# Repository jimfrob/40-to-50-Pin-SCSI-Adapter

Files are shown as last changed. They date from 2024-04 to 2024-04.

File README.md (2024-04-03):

I had a spare PowerBook version of a BlueSCSI v2 and wanted to make use of it, so I designed a PCB to adapt the 40-pin connector of the PowerBook to the standard 50-pin connector. I then designed a mount for installing it in a computer. The BlueSCSI is intended to be soldered on top of the board with the 40-pin header between. The power connector may be extranneous since the BlueSCSI should be able to take termination power.

40-pin header: Digikey part number [62004021121](https://www.digikey.com/en/products/detail/würth-elektronik/62004021121/15672211?s=N4IgTCBcDaIGxgAyICyLARg5kBdAvkA)

50-pin header: Digikey part number [SBH11-PBPC-D25-ST-BK](https://www.digikey.com/en/products/detail/sullins-connector-solutions/SBH11-PBPC-D25-ST-BK/1990069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)

Any 4-pin header should work for power for use with a floppy drive berg connector.

The board was designed with KiCad 8.



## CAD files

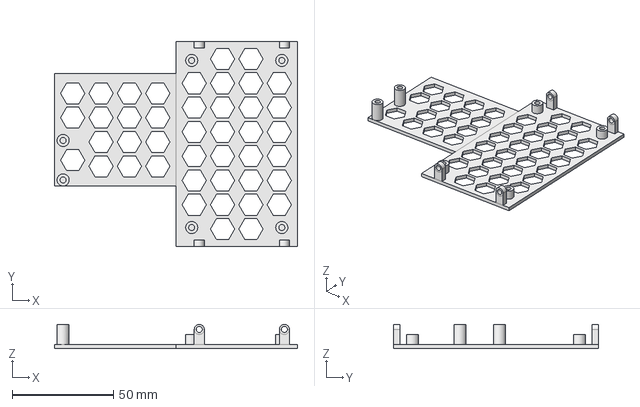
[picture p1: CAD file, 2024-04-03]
SCSI-Adapter-Mount-2.FCStd
120.0 x 101.0 x 12.0 mm

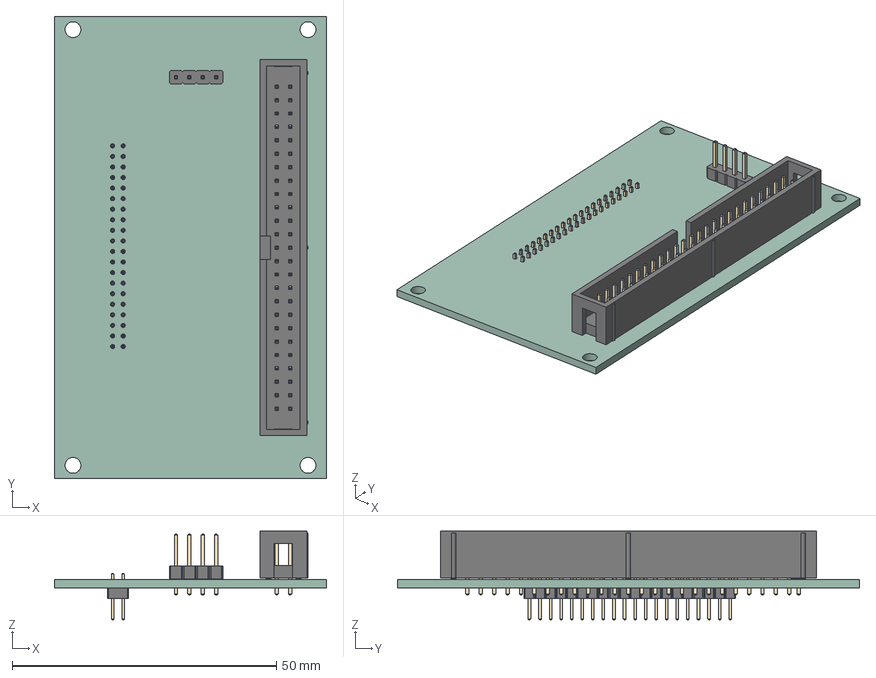
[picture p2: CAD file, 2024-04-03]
SCSI-Adapter.step
51.5 x 87.5 x 16.8 mm
IDC_Header_2x25_P254mm_Vertical
PinHeader_1x04_P254mm_Vertical
PinHeader_2x20_P200mm_Vertical
SCSI-Adapter_PCB

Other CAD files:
SCSI-Adapter-Mount-2-Body.stl

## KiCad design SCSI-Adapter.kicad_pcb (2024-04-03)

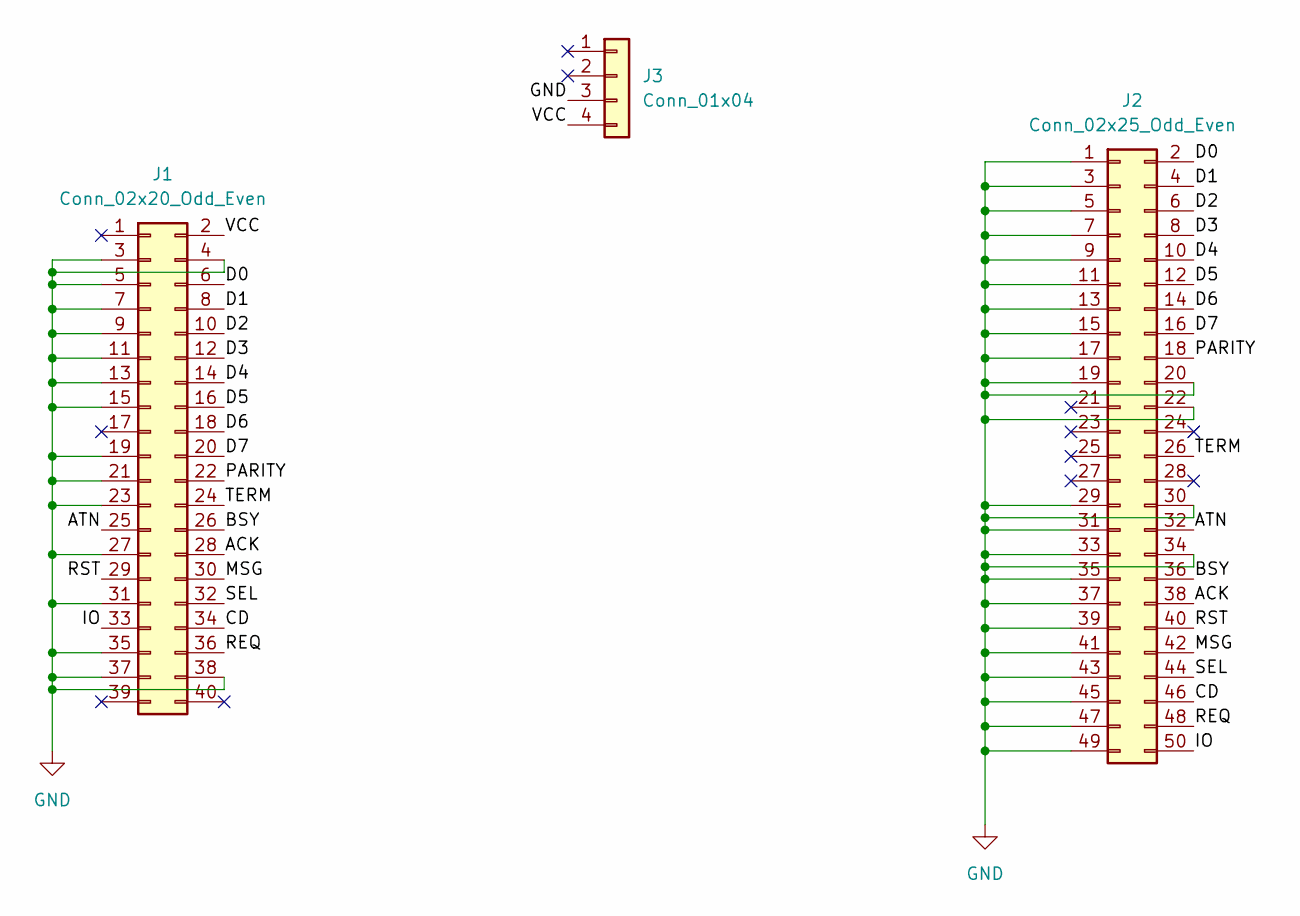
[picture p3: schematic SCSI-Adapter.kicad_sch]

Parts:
J1: Conn_02x20_Odd_Even; PinHeader_2x20_P2.00mm_Vertical
J2: Conn_02x25_Odd_Even; IDC-Header_2x25_P2.54mm_Vertical
J3: Conn_01x04; PinHeader_1x04_P2.54mm_Vertical

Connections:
/ACK: J1.28, J2.38
/ATN: J1.25, J2.32
/BSY: J1.26, J2.36
/CD: J1.34, J2.46
/D0: J1.6, J2.2
/D1: J1.8, J2.4
/D2: J1.10, J2.6
/D3: J1.12, J2.8
/D4: J1.14, J2.10
/D5: J1.16, J2.12
/D6: J1.18, J2.14
/D7: J1.20, J2.16
/IO: J1.33, J2.50
/MSG: J1.30, J2.42
/PARITY: J1.22, J2.18
/REQ: J1.36, J2.48
/RST: J1.29, J2.40
/SEL: J1.32, J2.44
/TERM: J1.24, J2.26
/VCC: J1.2, J3.4
GND: J1.3, J1.4, J1.5, J1.7, J1.9, J1.11, J1.13, J1.15, J1.19, J1.21, J1.23, J1.27, J1.31, J1.35, J1.37, J1.38, J2.1, J2.3, J2.5, J2.7, J2.9, J2.11, J2.13, J2.15, J2.17, J2.19, J2.20, J2.22, J2.29, J2.30, J2.31, J2.33, J2.34, J2.35, J2.37, J2.39, J2.41, J2.43, J2.45, J2.47, J2.49, J3.3

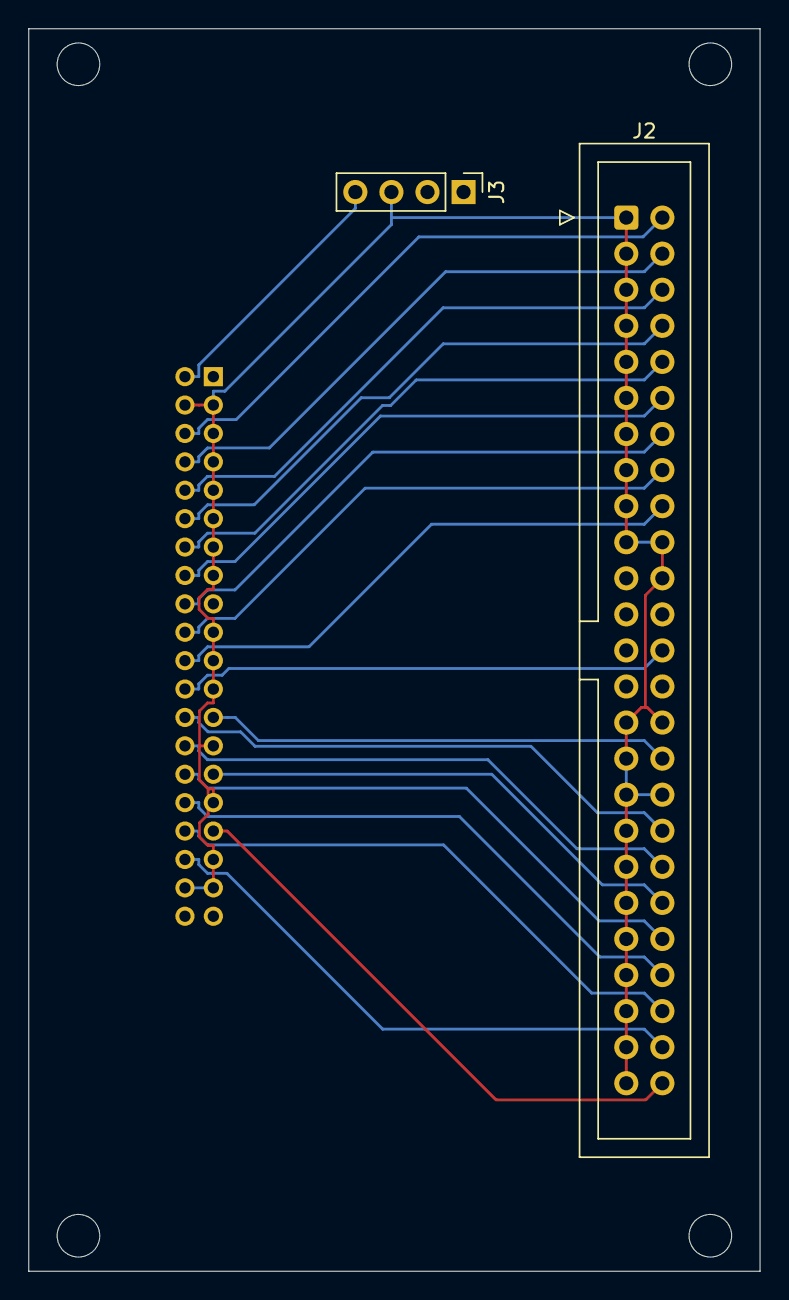
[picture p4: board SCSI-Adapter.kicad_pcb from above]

Board: 2 copper layers, 51.5 x 87.5 mm, 3 parts (1 on the bottom side), 21 nets.
